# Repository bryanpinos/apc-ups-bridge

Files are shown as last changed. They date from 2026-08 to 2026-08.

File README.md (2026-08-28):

# apc-ups-bridge

Read an **APC UPS over USB HID** with an ESP32-S3 and republish it to **MQTT** with
Home Assistant auto-discovery.

No host computer involved. The UPS plugs into the ESP32, not into your NAS or server,
which frees the USB port and removes the "my UPS monitor died because the machine it
was plugged into went down" problem.

```
APC UPS ──USB──> MAX3421E FeatherWing ──SPI──> ESP32-S3 ──WiFi──> MQTT ──> Home Assistant
```

## Why

The usual way to monitor a UPS is NUT or apcupsd on a machine plugged into it. That
works, but it consumes a USB port on the very machine the UPS exists to protect, and
the monitoring dies exactly when the host does.

This project started after a UPS failed with a genuine internal fault and announced it
by beeping — because nothing was watching it. A battery was replaced that didn't need
replacing. Every fault flag this firmware exposes (`NeedReplacement`, `Overload`,
`ShutdownImminent`) was available over USB the whole time.

## What it publishes

| Kind | Entities |
|---|---|
| Sensors | battery %, runtime (s), load %, input voltage, battery voltage, self-test result |
| Binary sensors | on mains, on battery, needs replacement, overload, shutdown imminent, below capacity limit |
| Diagnostics | WiFi RSSI, uptime, free heap, USB device VID:PID, USB attached, HID mounted, board battery |

Plus the raw HID report descriptor on `<base>/hid/descriptor`, which is how you adapt
it to a UPS this code has never seen.

## Hardware

| Part | Notes |
|---|---|
| **Adafruit ESP32-S3 Feather** (8 MB, no PSRAM) | Any ESP32-**S2/S3** Feather works. Classic ESP32 does **not** — Adafruit TinyUSB requires S2/S3. |
| **Adafruit USB Host FeatherWing (MAX3421E)** | CS = pin 10, IRQ = pin 9, fixed. Onboard 5 V/1 A boost supplies VBUS. |
| USB cable from the UPS | APC ships an RJ50-to-USB-A cable; it plugs straight into the wing's USB-A jack. |
| LiPo cell *(optional)* | Lets the monitor outlive the UPS it is monitoring. The Feather's MAX17048 reports its own charge. |

Stack the wing on the Feather. There is no other wiring.

**Why the wing instead of the S3's native USB host?** The ESP32-S3's USB-OTG and
USB-Serial-JTAG share a single PHY, so using native host mode costs you the serial
console. The MAX3421E runs over SPI and leaves native USB free.

## Build

Requires [PlatformIO](https://platformio.org/).

```bash
cp src/secrets.h.example src/secrets.h   # then edit it
pio run -e feather -t upload             # first flash over USB
```

After the first flash everything is over the air:

```bash
export OTA_HOST=192.168.0.50   # the board's IP
export OTA_PW=your-ota-password
pio run -e ota -t upload
```

`secrets.h` is gitignored and holds WiFi, MQTT, OTA and the per-unit identity.

### Running more than one

Set a distinct `UNIT_ID` / `UNIT_HOST` / `UNIT_NAME` per board in `secrets.h`.
Home Assistant derives entity_ids from **`UNIT_NAME`**, not `UNIT_ID`, so pick it
deliberately — renaming later renames every entity.

## MQTT topics

Base topic is `apcups/<UNIT_ID>/`.

| Topic | Payload |
|---|---|
| `status` | `online` / `offline` (LWT, retained) |
| `ups` | JSON: all decoded UPS state |
| `diag` | JSON: RSSI, uptime, heap, IP, hostname, USB state |
| `boot` | JSON: reset reason, firmware version (retained) |
| `stage` | boot-stage beacon (retained) |
| `hid/descriptor` | raw HID report descriptor, hex (retained) |
| `log` | free-text log lines |
| `cmd` | accepts `dump`, `diag`, `discovery`, `reboot` |

## Running a self-test

```bash
mosquitto_pub -h broker -t 'apcups/<unit>/cmd' -m selftest        # quick
mosquitto_pub -h broker -t 'apcups/<unit>/cmd' -m selftest_deep
mosquitto_pub -h broker -t 'apcups/<unit>/cmd' -m selftest_abort
```

Watch `<base>/ups`: `discharging` flips true while the inverter carries the load,
then `test` settles on `passed` / `warning` / `error` / `aborted`.

**The report id must be prefixed to the SET_REPORT payload.** TinyUSB already puts
it in `wValue`, which is what the HID spec requires, and the transfer is *accepted*
either way — but this APC firmware silently ignores a payload-only write and does
nothing at all. Verified both directions: payload-only never starts a test,
id-prefixed always does. Consistent with GET_REPORT on this device returning
`21 06` (report id, then value).

**The UPS will refuse a test while the battery is recharging.** After a test it sits
around 93 % for a while, and a further request is accepted, resets the state to
"no test initiated", and then does nothing. That is the UPS protecting itself, not
a bug — wait for it to reach full charge.

⚠️ A self-test transfers everything on the battery-backed outlets to the inverter
for a few seconds. If the inverter is faulty, that load drops.

## Adapting to a different UPS

**The report map is model-specific — do not assume this one fits your UPS.** The
firmware dumps the descriptor unprompted, so adapting is mechanical:

```bash
mosquitto_sub -h broker -t 'apcups/<unit>/hid/descriptor' -C 1 > mine.hex
python3 tools/parse_hid.py mine.hex
```

`parse_hid.py` prints every field as *report id / bit offset / bit size / usage name /
logical range*. Then edit `POLL[]` and `applyReport()` in `src/main.cpp` to match.

### Reference map: APC Back-UPS Pro BR1500MS2 (`051d:0002`)

```
Rpt 22 (2B)  PresentStatus bitfield -- the entire status word in one read
   bit0 Charging   bit1 Discharging  bit2 ACPresent  bit3 BatteryPresent
   bit4 BelowRemainingCapacityLimit  bit5 ShutdownImminent
   bit6 RemainingTimeLimitExpired    bit7 CommunicationLost
   bit8 NeedReplacement              bit9 Overload   bit10 VoltageNotRegulated
Rpt 12 (3B)  RemainingCapacity (8b) + RunTimeToEmpty (16b, seconds)
Rpt 80 (1B)  PercentLoad %
Rpt 33 (1B)  Test result: 1 passed, 2 warning, 3 error, 4 aborted,
                          5 in progress, 6 no test initiated, 7 scheduled
Rpt 49 (2B)  Input voltage, volts
Rpt  9 (2B)  Battery voltage, raw/100 (24 V pack reads ~2730 -> 27.30 V)
Rpt 24 (1B)  AudibleAlarmControl 1..3
```

Battery voltage scaling differs by pack: a 12 V unit and a 24 V unit both report
hundredths, so check the value against the nominal pack voltage rather than trusting
the HID unit exponent, which APC populates oddly.

## Gotchas

Everything here cost real debugging time. If you are building something similar,
read this section first.

**`USBHost.task()` blocks forever by default.** The signature is
`task(uint32_t timeout_ms = UINT32_MAX, ...)`. Under FreeRTOS it sleeps until a USB
event arrives, so with nothing attached the first call in `loop()` never returns.
WiFi stays associated and pings still answer — because that is a different task — so
it looks like a network bug. **Always call `USBHost.task(0)`.**

**TinyUSB silently refuses report descriptors over 256 bytes.** `hid_host.c` checks
`report_desc_len > CFG_TUH_ENUMERATION_BUFSIZE` and calls the mount callback with
`NULL, 0`. That constant is not `#ifndef`-guarded, so `-D` cannot override it. APC
descriptors are ~1 kB. Fetch it yourself with the public
`tuh_descriptor_get_hid_report()` into your own buffer.

**Use the async USB APIs, never the `_sync` variants.** `loop()` is what calls
`USBHost.task(0)`, so a blocking sync call from `loop()` deadlocks the stack — nothing
is left to service it. Report polling is a one-request-in-flight state machine
advanced from `tuh_hid_get_report_complete_cb()`.

**`-DARDUINO_USB_MODE=1` is required.** Otherwise the Arduino core links its own
`libarduino_tinyusb.a` and you get dozens of `multiple definition of 'usbd_*'` link
errors against Adafruit TinyUSB.

**After an esptool USB flash, an ESP32-S3 can stay latched in ROM download mode.**
`Hard resetting via RTS pin` does not always clear it. It enumerates as Espressif
`303a:1001` and esptool talks to it happily while your app never runs. **Physically
unplug and replug USB.** Tell: with `ARDUINO_USB_MODE=0`, a running app must present
the board's own USB IDs — still seeing Espressif's means it is not executing.

**Do not trust the serial console for bring-up.** On this board HWCDC produced no
output at all, in either USB mode, via raw termios, `screen`, or `pio device monitor`.
The retained `stage` topic is what actually located the hang: publish a boot-stage
beacon at each step of `setup()` and read the last value that stuck.

**`WiFi.setHostname()` must be called before `WiFi.mode()`.** It only writes a static
buffer; the value is pushed to the interface inside `WiFiGenericClass::mode()`. Call
it after and you silently get the MAC-derived default. Worse, `WiFi.getHostname()`
reads that same buffer, so it reports the name you set even when the interface is
using the default — verify with mDNS instead.

**Pin PlatformIO's platform version.** `platform = espressif32` may resolve to a
release that requires a newer core than your stable PlatformIO. This project pins
`espressif32@6.9.0`.

## Repository layout

```
platformio.ini          build envs: feather (USB), ota (network), mintest (bisect)
case/                   parametric OpenSCAD enclosure + STLs
src/main.cpp            firmware
src/secrets.h.example   template for the gitignored secrets.h
tools/parse_hid.py      HID report descriptor parser -> field map
tools/br1500ms2.hex     reference descriptor from a BR1500MS2
```

The `mintest` env builds a bare sketch with no libraries — useful for bisecting
whether a problem is your code or the board.

## Enclosure

A parametric OpenSCAD case for the stacked Feather + wing lives in
[`case/`](case/), with ready-to-print STLs. Both short ends are open by design —
the two connectors sit at opposite ends and different heights, so no horizontal
parting line works for both. Print `ups-bridge-fittest.stl` first.

## License

MIT — see [LICENSE](LICENSE).

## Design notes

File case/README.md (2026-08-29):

# Enclosure

Parametric OpenSCAD case for an Adafruit ESP32-S3 Feather with a USB Host
FeatherWing stacked on top. Two parts, both print flat, no supports.

```bash
OPENSCAD=/Applications/OpenSCAD.app/Contents/MacOS/OpenSCAD   # macOS
$OPENSCAD -o stl/ups-bridge-base.stl    -D 'part="base"'    case.scad
$OPENSCAD -o stl/ups-bridge-lid.stl     -D 'part="lid"'     case.scad
$OPENSCAD -o stl/ups-bridge-fittest.stl -D 'part="fittest"' case.scad
```

Outer footprint is about **57 x 28 mm**; assembled height depends on your stack.

## Three parts: base, lid, face plate

Both USB ports exit the same end. That end is left **fully open** in the base and
lid, and closed afterwards by a **face plate** carrying one exact hole per
connector. The far end is a solid wall.

This is the only arrangement that gives two clean openings. A connector can only
pass through an opening that is open in the direction of assembly, so a
base/lid parting line would have to run through *both* connectors — impossible
when one sits at ~7 mm and the other at ~22 mm. Whichever you do not split
through becomes an ugly full-height slot.

The face plate also **retains the board**: the stack drops into the base, the lid
goes on, then the plate presses into the open end and blocks the only escape
route. No screws or clips.

Assembly order: stack into base → lid on → face plate pressed in.

Set `conn_end` to `+1` or `-1` to choose which end the connectors face, and
`face_fit` for the press-fit interference (0.25 mm per side by default).

### Size the openings for the PLUG, not the connector

The first revision sized each hole to the receptacle body and produced a plate
you could not plug into. Two things matter:

* **The plug's overmold is far larger than the receptacle** it mates with, and it
  has to clear the plate.
* **Plate thickness eats insertion depth.** Every millimetre of plate is a
  millimetre of plug shell that cannot reach the connector. The plate is now
  2.4 mm total (was 4.0), and each opening is chamfered on the outer face so an
  overmold can nose in rather than butting against a flat surface.

`usbc_w/h` and `usba_w/h` are therefore **plug overmold dimensions**, not
connector dimensions.

### Print the face plate first

It is a two-minute print and it is the only part whose fit depends on connector
positions rather than board outline. Offer it up to the assembled stack before
committing filament to the base and lid. Adjust `usbc_*` / `usba_*` if the holes
do not line up — `usbc_z` and `usba_z` are heights above the **cavity floor**,
and `usbc_y` / `usba_y` are lateral offsets from the centreline.

## Print the fit test first

`ups-bridge-fittest.stl` is a ~10 mm slice of the base — a few minutes of
filament. It proves the cavity width and the corner posts before you commit to
the full part.

It looks like two side rails with a small 90-degree tab at each end: those tabs
are the four corner posts the Feather rests on, and the board drops *between*
the rails and sits *on* the posts.

**The slice must be taller than the posts.** `fit_h` is derived as
`floor_t + under_h + pcb_t + 2`, which leaves 2 mm of wall standing above the
seated board. An earlier 6 mm version sliced the posts off level with the wall
tops, so a board laid in rested on top of everything and the width clearance
could not be tested at all.

## Dimensions

Measured on a real stack using plain male/female headers:

| Measurement | Value |
|---|---|
| Feather PCB bottom to wing PCB top | **14.0 mm** |
| Feather PCB bottom to top of USB-A shell | **21.0 mm** |

which give `stack_h = 10.8` (14.0 less two 1.6 mm PCBs) and `above_wing_h = 7.0`
(21.0 less 14.0). Plus 4.5 mm of clearance under the Feather for solder tails and
the LiPo lead, and 1.0 mm of headroom so the lid never presses on the USB-A shell:

```
cavity 26.5 mm tall   base 14.0 + lid 16.5   footprint 57.2 x 28.2 mm
```

**Re-measure if you use stacking headers** — they are taller than plain ones and
`stack_h` will grow.

## Suggested print settings

0.2 mm layers, 3 perimeters, 20% infill, PETG or PLA. No supports. The base
prints floor-down; the lid prints top-down (open side up).

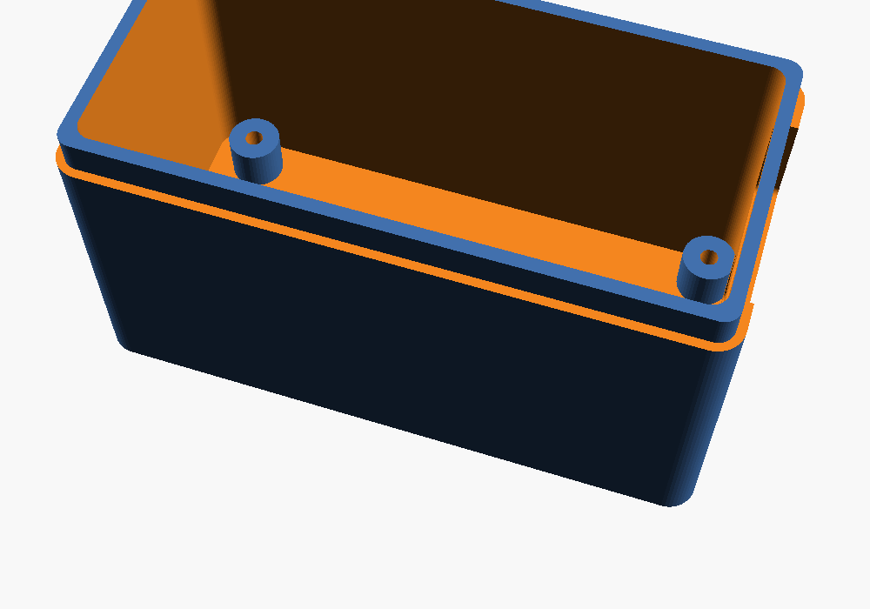
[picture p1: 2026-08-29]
case/preview-base-top.png

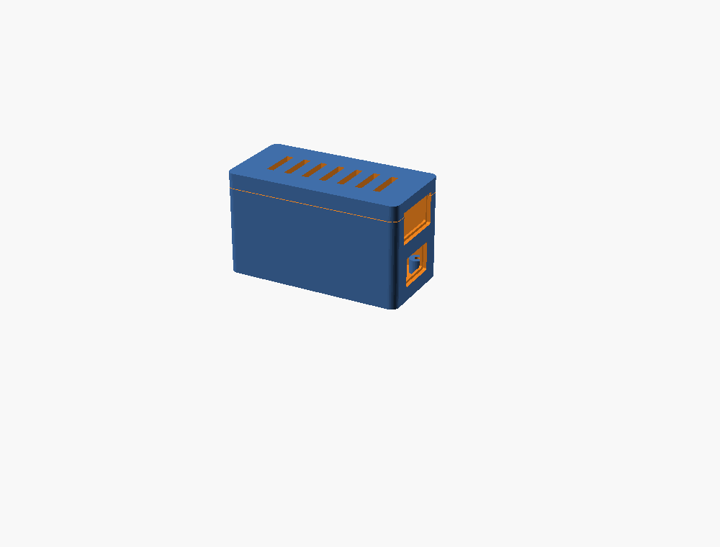
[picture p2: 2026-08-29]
case/preview-asm-0.png

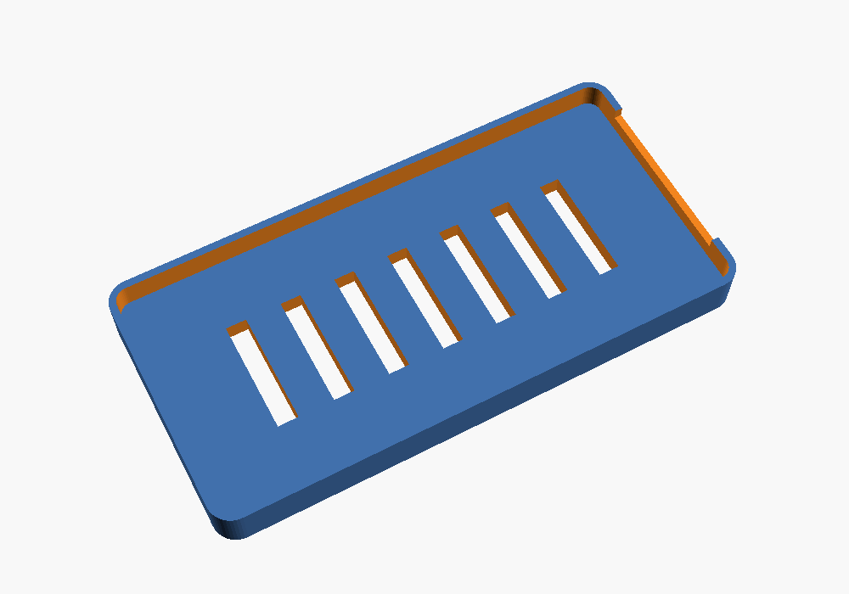
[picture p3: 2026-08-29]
case/preview-lid.png

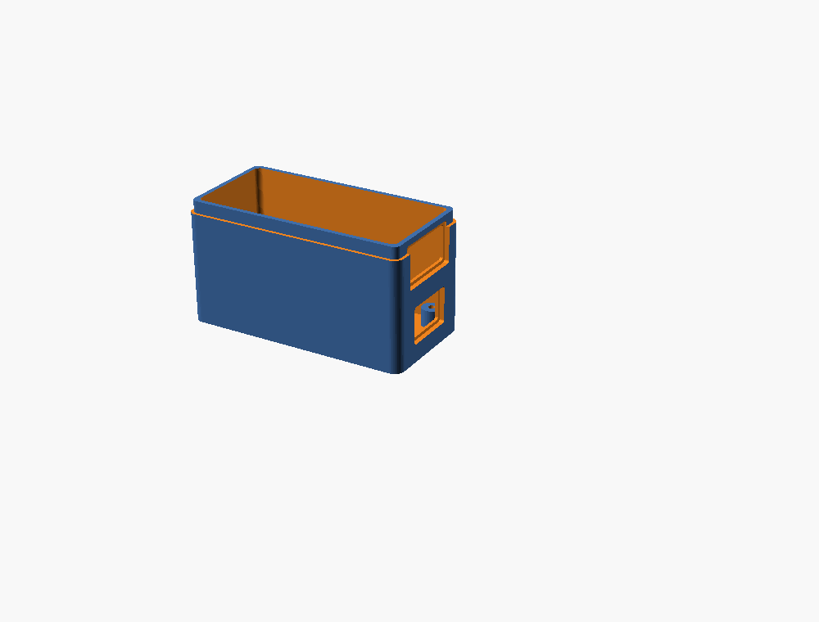
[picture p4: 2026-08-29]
case/preview-base.png

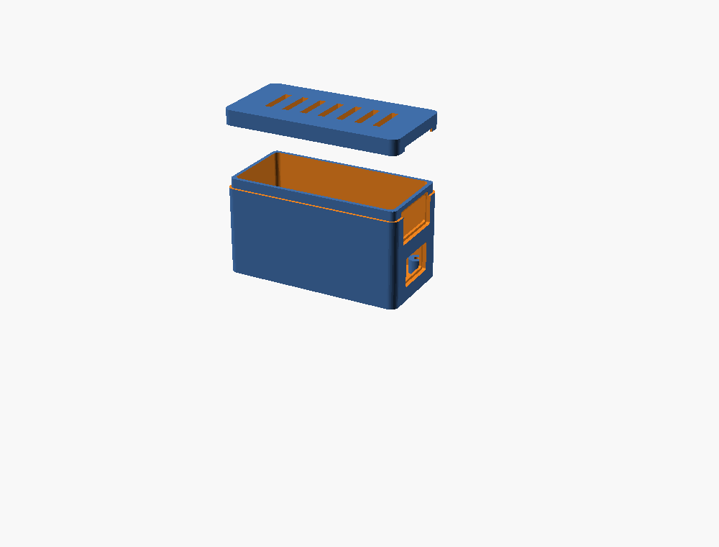
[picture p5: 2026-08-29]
case/preview-asm-1.png

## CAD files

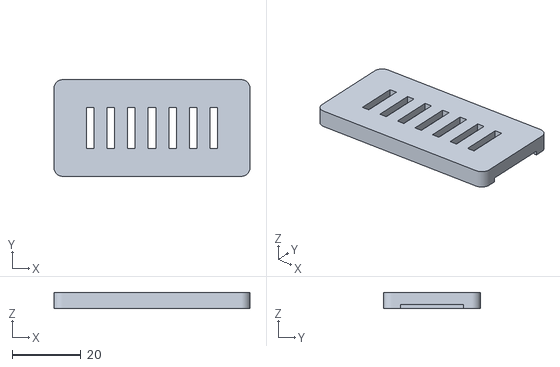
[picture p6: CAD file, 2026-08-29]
case/stl/ups-bridge-lid.stl
57.2 x 28.2 x 4.80

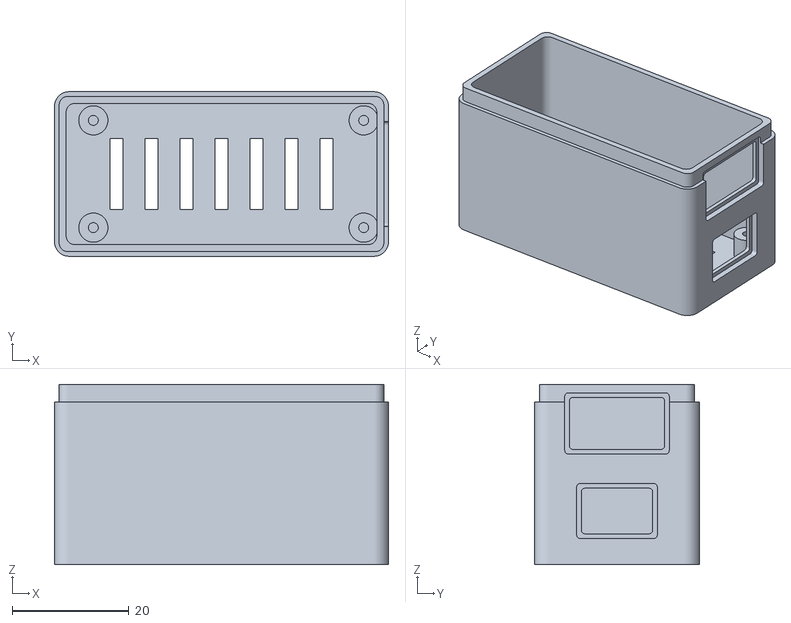
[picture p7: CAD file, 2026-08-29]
case/stl/ups-bridge-base.stl
57.2 x 28.2 x 30.9

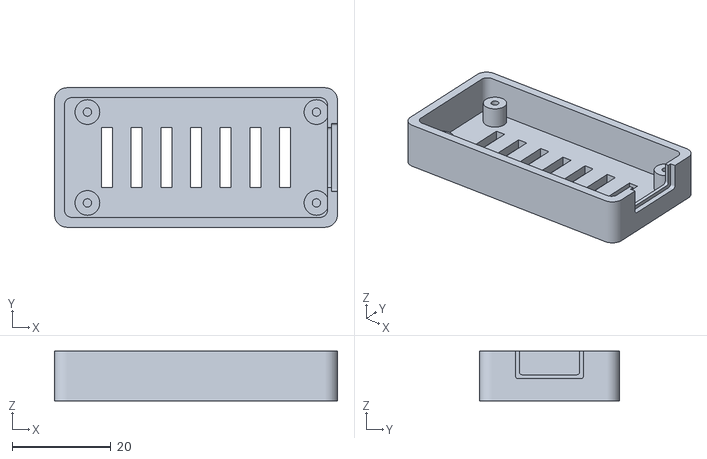
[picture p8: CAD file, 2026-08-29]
case/stl/ups-bridge-fittest.stl
57.2 x 28.2 x 10.1

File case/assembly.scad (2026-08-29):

// Assembly / exploded view. Not a printable part.
//   OpenSCAD -o out.png -D explode=1 assembly.scad
include <case.scad>;          // renders base() at the origin
explode = 0;
translate([0, 0, base_h + explode * 20]) lid();

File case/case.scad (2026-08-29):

// =============================================================================
//  UPS Bridge enclosure
//  Adafruit ESP32-S3 Feather + Adafruit USB Host FeatherWing (MAX3421E)
//  Companion to github.com/bryanpinos/apc-ups-bridge
//
//  Two parts, both print flat with no supports.
//
//  DESIGN NOTE: both USB ports exit the SAME end, and that end wall is SOLID,
//  carrying one hole per connector. The base is therefore full height and the
//  lid is only a cap.
//
//  This replaces an earlier three-part scheme (short base + tall lid + a separate
//  face plate pressed into an open end). That could not work: the slot that
//  opened the end removed the full width of it, so the face plate had nothing
//  left to register against, and the corner posts sat directly in its path.
//
//  The Feather goes in from above and is SCREWED to four bosses, which fixes its
//  position relative to the connector openings instead of leaving it to gravity.
//  Fit the Feather and its screws first, then plug the wing on top -- the wing
//  covers the Feather's mounting holes, and the 10.8 mm gap between the boards
//  clears the screw heads easily.
//    OpenSCAD -o out.stl -D 'part="base"'    case.scad
//    OpenSCAD -o out.stl -D 'part="lid"'     case.scad
//    OpenSCAD -o out.stl -D 'part="fittest"' case.scad   // 6 mm test slice
// =============================================================================

// ---------- BOARD DIMENSIONS -------------------------------------------------
// Feather spec is 50.8 x 22.86 mm; the Host wing is 52.0 x 22.8 x 8.8 mm.
// Cavity is sized to the larger footprint so both fit.
pcb_l        = 52.0;
pcb_w        = 23.0;
pcb_t        = 1.6;

// Measured on a real Feather + USB Host FeatherWing stack with plain male/
// female headers. Re-measure if you use stacking headers, which are taller.
stack_h      = 10.8;   // MEASURED: 14.0 overall (Feather PCB bottom -> wing PCB top)
                       //           minus two 1.6 mm PCBs = 10.8
above_wing_h = 7.4;    // MEASURED: 21.4 (Feather PCB bottom -> USB-A top)
                       //           minus 14.0 (to wing PCB top) = 7.4
headroom     = 3.0;    // air above the USB-A shell. Sets how much wall is left
                       // above the USB-A hole, whose top edge lands at 28.65 from
                       // the outer floor. Below ~2.3 the hole breaks out of the
                       // top of the base entirely.

under_h      = 4.5;    // clearance below the Feather for solder tails / LiPo lead

// ---------- CONNECTOR END ----------------------------------------------------
// Both USB ports exit the same end, through a solid 2 mm wall. The plug overmold
// -- not the receptacle -- is what has to pass through: the connectors sit ~2 mm
// behind the outer face, and a USB-A plug only has ~12 mm of shell against ~12 mm
// of insertion depth, so if the overmold could not enter the hole the plug would
// stop 2 mm short of seating. Size these to the actual cables that will live in
// this case; a chunky charging lead can be half again the size of a slim one.
conn_end     = 1;      // +1 or -1: which end the connectors face

usbc_plug_w  = 11.0;   // measured
usbc_plug_h  = 6.6;
usba_plug_w  = 15.1;   // measured
usba_plug_h  = 7.7;
plug_clear   = 1.2;    // total added, i.e. 0.6 per side. Deliberately loose: the
                       // centre heights below close to about +/-0.5 mm, and a
                       // plug that rattles slightly still mates -- one that is
                       // 0.4 mm proud of the hole does not.

// Connector CENTRE heights, from the FEATHER PCB BOTTOM -- the same datum as the
// 14.0 and 21.4 stack measurements. Closed out from three caliper readings:
//   wing PCB top          = 14.0   -> USB-A shell bottom (it sits flush)
//   USB-A top             = 21.4   -> USB-A spans 14.0..21.4, centre 17.7
//   clear gap between the = 10.2   -> USB-C top = 14.0 - 10.2 = 3.8, and it sits
//   two connector shells              on the Feather PCB top (1.6), so 1.6..3.8,
//                                     centre 2.7
// Note the USB-C body works out only 2.2 mm proud of the PCB, which means it is
// a mid-mount part sitting in a board cutout, not a 3.2 mm top-mount one. The
// three measurements close on each other, so trust them over the datasheet.
usbc_c       = 2.7;
usba_c       = 17.7;

usbc_w       = usbc_plug_w + plug_clear;
usbc_h       = usbc_plug_h + plug_clear;
usba_w       = usba_plug_w + plug_clear;
usba_h       = usba_plug_h + plug_clear;

// An undefined variable here does NOT fail: OpenSCAD warns, discards the whole
// transform, and draws the feature at the origin. That shipped a face plate with
// its USB-C opening 3.2 mm low. Fail loudly instead.
assert(is_num(usbc_c) && is_num(usba_c) && is_num(usbc_w) && is_num(usba_h),
       "connector opening dimensions must all be numbers");

// ---------- SHELL ------------------------------------------------------------
wall         = 2.0;
floor_t      = 2.0;
gap          = 0.6;    // per-side clearance around the PCB
corner_r     = 2.5;
// The lid drops OVER a rebated step on the tray rim. A short-lived inner-spigot
// version was tried and abandoned: it was given 0.3 mm per-side CLEARANCE, which
// aligns the lid and does nothing to hold it, so the lid simply fell off.
// Retention here is friction on the step, which means the bore must be sized to
// the step as PRINTED, not as modelled -- this printer runs internal dimensions
// roughly 0.4 mm large, enough on its own to turn a press fit into a rattle.
lip_h        = 3.0;    // rebate depth on the tray rim
lip_t        = 1.2;    // wall thickness left at the step

step_l       = 55.6;   // MEASURE the printed tray's step; nominal cav_l + 2*lip_t
step_w       = 26.6;   // MEASURE; nominal cav_w + 2*lip_t
skirt_fit    = 0.0;    // total added to the bore. 0 = line-to-line on the
                       // measured step. Negative = interference.
skirt_h      = 2.8;    // 0.2 mm shy of lip_h so the plate seats on the step top,
                       // not on the shoulder
vent_slots   = true;

part = "base";
$fn = 48;

// ---------- DERIVED ----------------------------------------------------------
cav_l     = pcb_l + 2*gap;
cav_w     = pcb_w + 2*gap;
cav_h     = under_h + pcb_t + stack_h + pcb_t + above_wing_h + headroom;
out_l     = cav_l + 2*wall;
out_w     = cav_w + 2*wall;
feather_z = under_h;                       // PCB underside above inner floor
wing_z    = under_h + pcb_t + stack_h;
// The base is now the whole box: it has to be tall enough to contain the USB-A
// hole in its own end wall. The lid is just a cap over the top.
base_h    = floor_t + cav_h;
lid_h     = floor_t;

// Rounded rectangular prism, centred in X/Y, sitting on z=0.
module rrect(l, w, h, r) {
  linear_extrude(height = h)
    offset(r = r) offset(delta = -r) square([l, w], center = true);
}

// ---------- SCREW BOSSES ------------------------------------------------------
// Four bosses aligned to the FEATHER's mounting holes (the wing stacks above and
// is not fastened). Bosses replace the plain corner posts the board used to rest
// on: screwing it down also pins it against the connector openings, so the plug
// heights stay true.
//
// Both measured: 3.5 mm from the board edge to the FAR side of the mounting
// hole (the same to the long and the short edge), and 2.5 mm hole diameter. The
// hole CENTRE is therefore 3.5 - 2.5/2 = 2.25 mm in from each edge.
feather_l    = 50.8;   // Feather spec, NOT the 52.0 wing footprint the cavity uses
feather_w    = 22.86;
hole_edge    = 3.5;    // MEASURED: board edge -> far side of the mounting hole
board_hole_d = 2.5;    // MEASURED
hole_inset   = hole_edge - board_hole_d/2;

boss_od      = 5.0;
screw_pilot  = 1.7;    // M2 self-tapping into PLA. Drill out to 2.05 for a
                       // machine screw and a nut, or 1.5 for a tighter bite.

// The Feather sits hard against the connector end, so its openings line up: its
// end edge is at the cavity end and the bosses are referenced back from there.
module posts() {
  for (px = [conn_end * (cav_l/2 - hole_inset),
             conn_end * (cav_l/2 - feather_l + hole_inset)],
       py = [-1, 1])
    translate([px, py * (feather_w/2 - hole_inset), floor_t])
      difference() {
        cylinder(h = under_h, d = boss_od);
        translate([0, 0, -0.5]) cylinder(h = under_h + 1, d = screw_pilot);
      }
}
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

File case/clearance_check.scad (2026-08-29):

// Test fixture, not a printable part. Places the lid where it actually sits and
// intersects it against real geometry. Any facets = interference.
//   OpenSCAD -o out.stl -D 'part="none"' -D 'check="realplug"' clearance_check.scad
// NOTE: an envelope that exactly matches a hole yields a ZERO-VOLUME artifact
// from coincident faces -- always check the facet count, not just whether an STL
// got written.
include <case.scad>;
check = "realplug";

module plug_envelope(c, w, h) {
  z = floor_t + under_h + c;
  translate([conn_end * (out_l/2 + 6), 0, z])
    rotate([0, 90, 0]) linear_extrude(height = 24, center = true) rr2(h, w, 0.6);
}
module board_volume() {
  translate([conn_end * (cav_l/2 - pcb_l/2), 0,
             floor_t + under_h + (pcb_t + stack_h + pcb_t + above_wing_h)/2])
    cube([pcb_l, pcb_w, pcb_t + stack_h + pcb_t + above_wing_h], center = true);
}
if (check == "realplug")            // actual plug overmolds through the assembly
  intersection() {
    union() { base(); translate([0,0,base_h]) lid(); }
    union() { plug_envelope(usbc_c, usbc_plug_w, usbc_plug_h);
              plug_envelope(usba_c, usba_plug_w, usba_plug_h); }
  }
if (check == "fit")                 // lid skirt vs tray step
  intersection() { base(); translate([0,0,base_h]) lid(); }
if (check == "board")               // lid vs the installed stack
  intersection() { translate([0,0,base_h]) lid(); board_volume(); }

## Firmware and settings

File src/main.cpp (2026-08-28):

// APC UPS -> MQTT bridge  |  v0.1 "diagnostics + OTA"
//
// Adafruit ESP32-S3 Feather (8MB, no PSRAM) + USB Host FeatherWing (MAX3421E)
//   MAX3421E: SPI, CS = pin 10, IRQ = pin 9   (FeatherWing defaults)
//   Native USB-C stays free for serial console -- host runs on rhport 1.
//
// This build does NOT decode UPS data yet. It brings up WiFi + OTA + MQTT,
// publishes diagnostics, and dumps the HID report descriptor of whatever
// USB device is attached so the decode layer can be written against it.

#include <Arduino.h>
#include <WiFi.h>
#include <ESPmDNS.h>
#include <ArduinoOTA.h>
#include <PubSubClient.h>
#include <ArduinoJson.h>
#include <Wire.h>
#include <Adafruit_MAX1704X.h>
#include "Adafruit_TinyUSB.h"
#include "SPI.h"
#include "secrets.h"
#include <esp_system.h>

// ----------------------------------------------------------------- config
static const char *FW_VERSION = "1.5.0";
// ===================== PER-UNIT IDENTITY =====================
// Define these in secrets.h (gitignored) to build a second bridge. Defaults below
// are placeholders so the project builds out of the box.
//   UNIT_ID   MQTT client id, topic base, HA unique_id prefix. Underscores ok.
//   UNIT_HOST Network hostname. RFC-1123: letters/digits/hyphens ONLY.
//   UNIT_NAME HA device name. NOTE: HA derives entity_ids from THIS, not UNIT_ID.
#ifndef UNIT_ID
#define UNIT_ID    "ups_bridge"
#endif
#ifndef UNIT_HOST
#define UNIT_HOST  "ups-bridge"
#endif
#ifndef UNIT_NAME
#define UNIT_NAME  "UPS Bridge"
#endif
// =============================================================

static const char *DEV_ID   = UNIT_ID;
static const char *DEV_NAME = UNIT_NAME;
static const char *NET_HOST = UNIT_HOST;

#define MAX3421_CS   10
#define MAX3421_INT   9

static const uint32_t DIAG_INTERVAL_MS   = 15000;
static const uint32_t MQTT_RETRY_MS      = 5000;
static const size_t   MQTT_BUFFER_BYTES  = 8192;

// ----------------------------------------------------------------- state
Adafruit_USBH_Host USBHost(&SPI, MAX3421_CS, MAX3421_INT);
Adafruit_MAX17048  fuelGauge;
bool fuelGaugeOk = false;

WiFiClient   net;
PubSubClient mqtt(net);

static char tBase[48], tStatus[80], tDiag[80], tDesc[80], tLog[80], tCmd[80], tStage[80], tBoot[80], tUps[80];

static volatile bool usbAttached = false;
static uint16_t usbVid = 0, usbPid = 0;
static uint8_t  usbDaddr = 0;

static bool     hidMounted = false;
static uint8_t  hidDaddr = 0, hidIdx = 0;
static uint16_t hidDescLen = 0;
static uint8_t  hidDesc[2048];
static bool     hidDescWanted = false;   // TinyUSB skipped it (>256B enum buf)
static bool     hidDescInFlight = false;
static bool     hidDescDirty = false;

struct UpsState {
  bool valid = false;
  // status flags
  bool charging=false, discharging=false, acPresent=false, batteryPresent=false;
  bool belowCapLimit=false, shutdownImminent=false, timeLimitExpired=false;
  bool commLost=false, needReplacement=false, overload=false, voltNotRegulated=false;
  int  capacity=-1;        // %
  long runtime=-1;         // seconds
  int  load=-1;            // %
  int  test=-1;
  long vin=-1;             // raw
  long vbatt=-1;           // raw
  int  alarm=-1;
} ups;

static uint32_t pollTimeouts = 0;
// loop() section timing -- worst case since the last diag publish
static uint32_t tmUsb = 0, tmOta = 0, tmMqtt = 0, tmPoll = 0, tmLoop = 0;
static uint8_t  setBuf[8];
static bool     rawDump = false;
static bool upsTest(uint8_t mode);   // defined with the poll machine

static uint32_t lastDiag = 0, lastMqttTry = 0;
static uint32_t bootMs = 0;

// ----------------------------------------------------------------- helpers
static void logf(const char *fmt, ...) {
  char buf[256];
  va_list ap; va_start(ap, fmt);
  vsnprintf(buf, sizeof(buf), fmt, ap);
  va_end(ap);
  Serial.println(buf);
  if (mqtt.connected()) mqtt.publish(tLog, buf);
}

static void publishDescriptor() {
  if (!hidDescLen || !mqtt.connected()) return;
  // hex-encode; 1024 bytes max -> 2048 chars, inside the 4k buffer
  static char hex[4200];
  size_t n = hidDescLen > sizeof(hidDesc) ? sizeof(hidDesc) : hidDescLen;
  for (size_t i = 0; i < n; i++) sprintf(hex + i * 2, "%02x", hidDesc[i]);
  hex[n * 2] = 0;
  mqtt.publish(tDesc, hex, true);
  logf("published HID report descriptor: %u bytes", (unsigned)hidDescLen);
  hidDescDirty = false;
}


// ----------------------------------------------------------------- wifi diagnostics
static const char *wifiStatusStr(int st) {
  switch (st) {
    case WL_IDLE_STATUS:     return "IDLE";
    case WL_NO_SSID_AVAIL:   return "NO_SSID_AVAIL";
    case WL_SCAN_COMPLETED:  return "SCAN_COMPLETED";
    case WL_CONNECTED:       return "CONNECTED";
    case WL_CONNECT_FAILED:  return "CONNECT_FAILED (auth?)";
    case WL_CONNECTION_LOST: return "CONNECTION_LOST";
    case WL_DISCONNECTED:    return "DISCONNECTED";
    default:                 return "UNKNOWN";
  }
}

static const char *authStr(int a) {
  switch (a) {
    case WIFI_AUTH_OPEN:            return "OPEN";
    case WIFI_AUTH_WEP:             return "WEP";
    case WIFI_AUTH_WPA_PSK:         return "WPA_PSK";
    case WIFI_AUTH_WPA2_PSK:        return "WPA2_PSK";
    case WIFI_AUTH_WPA_WPA2_PSK:    return "WPA/WPA2_PSK";
    case WIFI_AUTH_WPA2_ENTERPRISE: return "WPA2_ENTERPRISE";
    case WIFI_AUTH_WPA3_PSK:        return "WPA3_PSK";
    case WIFI_AUTH_WPA2_WPA3_PSK:   return "WPA2/WPA3_PSK";
    default:                        return "other";
  }
}

// Does NOT print the SSID itself -- only whether the configured one is visible.
// The ESP32-S3 radio is 2.4 GHz only, so "NOT FOUND" usually means the SSID is
// 5 GHz-only, hidden, or misspelled.
static void wifiScanReport() {
  int n = WiFi.scanNetworks(false, true);
  Serial.printf("[wifi] scan: %d networks visible on 2.4GHz\n", n);
  bool found = false;
  for (int i = 0; i < n; i++) {
    if (WiFi.SSID(i) == String(WIFI_SSID)) {
      found = true;
      Serial.printf("[wifi] configured SSID FOUND  ch=%d rssi=%d auth=%s\n",
                    WiFi.channel(i), (int)WiFi.RSSI(i),
                    authStr(WiFi.encryptionType(i)));
      break;
    }
  }
  if (!found)
    Serial.println("[wifi] configured SSID NOT FOUND on 2.4GHz "
                   "(5GHz-only? hidden? typo?)");
  WiFi.scanDelete();
}

// ----------------------------------------------------------------- HA discovery
static void haSensor(const char *key, const char *name, const char *unit,
                     const char *devclass, const char *tmpl, bool diagnostic) {
  char topic[160];
  snprintf(topic, sizeof(topic), "homeassistant/sensor/%s_%s/config", DEV_ID, key);

  JsonDocument d;
  d["name"] = name;
  d["uniq_id"] = String(DEV_ID) + "_" + key;
  d["stat_t"] = tDiag;
  d["val_tpl"] = tmpl;
  d["avty_t"] = tStatus;
  d["pl_avail"] = "online";
  d["pl_not_avail"] = "offline";
  if (unit && *unit)         d["unit_of_meas"] = unit;
  if (devclass && *devclass) d["dev_cla"] = devclass;
  if (diagnostic)            d["ent_cat"] = "diagnostic";
  JsonObject dev = d["dev"].to<JsonObject>();
  dev["ids"][0] = DEV_ID;
  dev["name"] = DEV_NAME;
  dev["mf"] = "DIY";
  dev["mdl"] = "ESP32-S3 Feather + MAX3421E";
  dev["sw"] = FW_VERSION;

  char out[768];
  size_t n = serializeJson(d, out, sizeof(out));
  mqtt.publish(topic, (const uint8_t *)out, n, true);
}

static void haBinary(const char *key, const char *name, const char *devclass,
                     const char *tmpl) {
  char topic[160];
  snprintf(topic, sizeof(topic), "homeassistant/binary_sensor/%s_%s/config", DEV_ID, key);

  JsonDocument d;
  d["name"] = name;
  d["uniq_id"] = String(DEV_ID) + "_" + key;
  d["stat_t"] = tDiag;
  d["val_tpl"] = tmpl;
  d["pl_on"] = "true";
  d["pl_off"] = "false";
  d["avty_t"] = tStatus;
  d["pl_avail"] = "online";
  d["pl_not_avail"] = "offline";
  if (devclass && *devclass) d["dev_cla"] = devclass;
  d["ent_cat"] = "diagnostic";
  JsonObject dev = d["dev"].to<JsonObject>();
  dev["ids"][0] = DEV_ID;
  dev["name"] = DEV_NAME;
  dev["mf"] = "DIY";
  dev["mdl"] = "ESP32-S3 Feather + MAX3421E";
  dev["sw"] = FW_VERSION;

  char out[768];
  size_t n = serializeJson(d, out, sizeof(out));
  mqtt.publish(topic, (const uint8_t *)out, n, true);
}


static void haUps() {
  struct S { const char *k,*n,*u,*dc,*t; };
  static const S sensors[] = {
    {"capacity","UPS battery","%","battery","{{ value_json.capacity }}"},
    {"runtime","UPS runtime","s","duration","{{ value_json.runtime_s }}"},
    {"load","UPS load","%","power_factor","{{ value_json.load_pct }}"},
    {"input_v","UPS input voltage","V","voltage","{{ value_json.input_v }}"},
    {"battery_v","UPS battery voltage","V","voltage","{{ value_json.battery_v }}"},
    {"test","UPS self-test",NULL,NULL,"{{ value_json.test }}"},
  };
  for (auto &x : sensors) {
    char topic[160];
    snprintf(topic, sizeof(topic), "homeassistant/sensor/%s_%s/config", DEV_ID, x.k);
    JsonDocument d;
    d["name"] = x.n; d["uniq_id"] = String(DEV_ID) + "_" + x.k;
    d["stat_t"] = tUps; d["val_tpl"] = x.t;
    d["avty_t"] = tStatus; d["pl_avail"]="online"; d["pl_not_avail"]="offline";
    if (x.u)  d["unit_of_meas"] = x.u;
    if (x.dc) d["dev_cla"] = x.dc;
    JsonObject dev = d["dev"].to<JsonObject>();
    dev["ids"][0]=DEV_ID; dev["name"]=DEV_NAME; dev["mf"]="DIY";
    dev["mdl"]="ESP32-S3 Feather + MAX3421E"; dev["sw"]=FW_VERSION;
    char out[768]; size_t n = serializeJson(d, out, sizeof(out));
    mqtt.publish(topic, (const uint8_t*)out, n, true);
  }
  struct B { const char *k,*n,*dc,*t; };
  static const B bins[] = {
    {"ac_present","UPS on mains","power","{{ value_json.ac_present }}"},
    {"discharging","UPS on battery","battery_charging","{{ value_json.discharging }}"},
    {"need_replacement","UPS battery needs replacement","problem","{{ value_json.need_replacement }}"},
    {"overload","UPS overload","problem","{{ value_json.overload }}"},
    {"shutdown_imminent","UPS shutdown imminent","problem","{{ value_json.shutdown_imminent }}"},
    {"below_cap_limit","UPS below capacity limit","problem","{{ value_json.below_cap_limit }}"},
  };
  for (auto &x : bins) {
    char topic[160];
    snprintf(topic, sizeof(topic), "homeassistant/binary_sensor/%s_%s/config", DEV_ID, x.k);
    JsonDocument d;
    d["name"]=x.n; d["uniq_id"]=String(DEV_ID)+"_"+x.k;
    d["stat_t"]=tUps; d["val_tpl"]=x.t; d["pl_on"]="true"; d["pl_off"]="false";
    d["avty_t"]=tStatus; d["pl_avail"]="online"; d["pl_not_avail"]="offline";
    if (x.dc) d["dev_cla"]=x.dc;
    JsonObject dev = d["dev"].to<JsonObject>();
    dev["ids"][0]=DEV_ID; dev["name"]=DEV_NAME; dev["mf"]="DIY";
    dev["mdl"]="ESP32-S3 Feather + MAX3421E"; dev["sw"]=FW_VERSION;
    char out[768]; size_t n = serializeJson(d, out, sizeof(out));
    mqtt.publish(topic, (const uint8_t*)out, n, true);
  }
  logf("HA UPS discovery published");
}

static void publishDiscovery() {
  haSensor("rssi", "WiFi RSSI", "dBm", "signal_strength", "{{ value_json.rssi }}", true);
  haSensor("uptime", "Uptime", "s", "duration", "{{ value_json.uptime_s }}", true);
  haSensor("heap", "Free heap", "B", "data_size", "{{ value_json.heap_free }}", true);
  haSensor("batt_v", "Backup battery voltage", "V", "voltage", "{{ value_json.batt_v }}", true);
  haSensor("batt_pct", "Backup battery", "%", "battery", "{{ value_json.batt_pct }}", true);
  haSensor("usb_id", "USB device", "", "", "{{ value_json.usb_id }}", true);
  haBinary("usb_attached", "USB device attached", "connectivity", "{{ value_json.usb_attached }}");
  haBinary("hid_mounted", "HID interface mounted", "connectivity", "{{ value_json.hid_mounted }}");
  haUps();
  logf("HA discovery published");
}

// ----------------------------------------------------------------- diagnostics
static void publishDiag() {
  JsonDocument d;
  d["fw"]          = FW_VERSION;
  d["uptime_s"]    = (millis() - bootMs) / 1000;
  d["rssi"]        = WiFi.RSSI();
  d["ip"]          = WiFi.localIP().toString();
  d["hostname"]    = WiFi.getHostname();
  d["heap_free"]   = ESP.getFreeHeap();
  d["heap_min"]    = ESP.getMinFreeHeap();
  d["usb_attached"] = usbAttached ? "true" : "false";
  d["hid_mounted"]  = hidMounted ? "true" : "false";
  d["hid_desc_len"] = hidDescLen;
  d["poll_timeouts"] = pollTimeouts;
  d["t_loop_ms"] = tmLoop;  d["t_usb_ms"] = tmUsb;  d["t_ota_ms"] = tmOta;
  d["t_mqtt_ms"] = tmMqtt;  d["t_poll_ms"] = tmPoll;
  tmLoop = tmUsb = tmOta = tmMqtt = tmPoll = 0;
  d["ups_valid"]    = ups.valid ? "true" : "false";

  char idbuf[16] = "none";
  if (usbAttached) snprintf(idbuf, sizeof(idbuf), "%04x:%04x", usbVid, usbPid);
  d["usb_id"] = idbuf;

  if (fuelGaugeOk) {
    d["batt_v"]   = serialized(String(fuelGauge.cellVoltage(), 3));
    d["batt_pct"] = serialized(String(fuelGauge.cellPercent(), 1));
  } else {
    d["batt_v"]   = nullptr;
    d["batt_pct"] = nullptr;
  }

  char out[512];
  size_t n = serializeJson(d, out, sizeof(out));
  mqtt.publish(tDiag, (const uint8_t *)out, n, false);
}

// ----------------------------------------------------------------- MQTT
static void onMqtt(char *topic, byte *payload, unsigned int len) {
  String cmd; for (unsigned i = 0; i < len; i++) cmd += (char)payload[i];
  cmd.trim();
  logf("cmd: %s", cmd.c_str());
  if (cmd == "dump")        publishDescriptor();
  else if (cmd == "diag")   publishDiag();
  else if (cmd == "discovery") publishDiscovery();
  else if (cmd == "reboot") { mqtt.publish(tStatus, "offline", true); delay(200); ESP.restart(); }
  else if (cmd == "selftest")      logf("self-test quick: %s", upsTest(1) ? "submitted" : "submit FAILED");
  else if (cmd == "selftest_deep") logf("self-test deep: %s",  upsTest(2) ? "submitted" : "submit FAILED");
  else if (cmd == "selftest_abort")logf("self-test abort: %s", upsTest(3) ? "submitted" : "submit FAILED");
  else if (cmd == "raw33") { rawDump = true; logf("will dump raw report 33"); }
}

static void mqttConnect() {
  if (millis() - lastMqttTry < MQTT_RETRY_MS) return;
  lastMqttTry = millis();
  if (!mqtt.connect(DEV_ID, nullptr, nullptr, tStatus, 0, true, "offline")) return;
  mqtt.publish(tStatus, "online", true);
  mqtt.subscribe(tCmd);
  publishDiscovery();
  publishDiag();
  if (hidDescLen) publishDescriptor();
  Serial.printf("MQTT connected to %s:%d\n", MQTT_HOST, MQTT_PORT);
}

// ----------------------------------------------------------------- TinyUSB callbacks
extern "C" {

void tuh_mount_cb(uint8_t daddr) {
  usbDaddr = daddr;
  usbAttached = true;
  tuh_vid_pid_get(daddr, &usbVid, &usbPid);
  Serial.printf("[usb] attached addr=%u  %04x:%04x\n", daddr, usbVid, usbPid);
}

void tuh_umount_cb(uint8_t daddr) {
  (void)daddr;
  usbAttached = false;
  hidMounted = false;
  hidDescLen = 0;
  usbVid = usbPid = 0;
  Serial.printf("[usb] detached addr=%u\n", daddr);
}

void tuh_hid_mount_cb(uint8_t daddr, uint8_t idx,
                      uint8_t const *report_desc, uint16_t desc_len) {
  hidDaddr = daddr; hidIdx = idx; hidMounted = true;
  if (desc_len == 0 || report_desc == NULL) {
    // TinyUSB skips descriptors larger than CFG_TUH_ENUMERATION_BUFSIZE (256).
    // APC descriptors exceed that, so fetch it ourselves into a bigger buffer.
    hidDescLen = 0;
    hidDescWanted = true;
    Serial.println("[hid] descriptor skipped by stack (>256B) - will fetch manually");
  } else {
    hidDescLen = desc_len;
    uint16_t n = desc_len > sizeof(hidDesc) ? sizeof(hidDesc) : desc_len;
    memcpy(hidDesc, report_desc, n);
    hidDescDirty = true;
  }
  Serial.printf("[hid] mounted daddr=%u idx=%u desc_len=%u\n", daddr, idx, desc_len);
}

void tuh_hid_umount_cb(uint8_t daddr, uint8_t idx) {
  (void)daddr; (void)idx;
  hidMounted = false;
  Serial.println("[hid] unmounted");
}

void tuh_hid_report_received_cb(uint8_t daddr, uint8_t idx,
                                uint8_t const *report, uint16_t len) {
  (void)daddr; (void)idx; (void)report; (void)len;
  // v0.1: not consuming interrupt reports yet
}

} // extern "C"



static const char *resetReasonStr(esp_reset_reason_t r) {
  switch (r) {
    case ESP_RST_POWERON:  return "POWERON";
    case ESP_RST_EXT:      return "EXT_RESET";
    case ESP_RST_SW:       return "SW_RESTART";
    case ESP_RST_PANIC:    return "PANIC (crash)";
    case ESP_RST_INT_WDT:  return "INT_WDT";
    case ESP_RST_TASK_WDT: return "TASK_WDT";
    case ESP_RST_WDT:      return "OTHER_WDT";
    case ESP_RST_BROWNOUT: return "BROWNOUT (power)";
    case ESP_RST_DEEPSLEEP:return "DEEPSLEEP";
    case ESP_RST_SDIO:     return "SDIO";
    default:               return "UNKNOWN";
  }
}

// Boot-stage beacon: a headless board must be able to say how far it got.
// Published retained, so the last successful stage survives a hang.
static void stage(const char *s) {
  Serial.printf("[stage] %s\n", s);
  if (mqtt.connected()) { mqtt.publish(tStage, s, true); mqtt.loop(); }
}

// Blocking-with-timeout connect used during setup only.
static bool mqttConnectBlocking(uint32_t timeoutMs) {
  uint32_t t0 = millis();
  while (millis() - t0 < timeoutMs) {
    if (mqtt.connected()) return true;
    if (mqtt.connect(DEV_ID, nullptr, nullptr, tStatus, 0, true, "offline")) {
      mqtt.publish(tStatus, "online", true);
      mqtt.subscribe(tCmd);
      return true;
    }
    delay(500);
  }
  return false;
}


// Manual report-descriptor fetch (async; a sync call from loop() would deadlock
// the USB stack, since loop() is also what services USBHost.task()).
static void descFetchDone(tuh_xfer_t *xfer) {
  hidDescInFlight = false;
  if (xfer->result == XFER_RESULT_SUCCESS) {
    hidDescLen = (uint16_t)xfer->actual_len;
    hidDescDirty = true;
    hidDescWanted = false;
    Serial.printf("[hid] fetched report descriptor: %u bytes\n", hidDescLen);
  } else {
    Serial.printf("[hid] descriptor fetch failed, result=%d\n", (int)xfer->result);
  }
}

static void hidDescFetchTick() {
  if (!hidDescWanted || hidDescInFlight || !hidMounted) return;
  tuh_itf_info_t info;
  if (!tuh_hid_itf_get_info(hidDaddr, hidIdx, &info)) return;
  hidDescInFlight = true;
  bool ok = tuh_descriptor_get_hid_report(hidDaddr, info.desc.bInterfaceNumber,
                                          0x22 /* HID report descriptor */, 0,
                                          hidDesc, sizeof(hidDesc),
                                          descFetchDone, 0);
  if (!ok) { hidDescInFlight = false; }
  else     { Serial.println("[hid] descriptor fetch requested"); }
}


// ----------------------------------------------------------------- UPS polling
// Report map derived from this unit's own 1049-byte descriptor (tools/parse_hid.py).
// tuh_hid_get_report() is ASYNC: one request in flight, completion arrives in
// tuh_hid_get_report_complete_cb(), then we advance to the next report.
struct PollItem { uint8_t id; uint8_t len; };
static const PollItem POLL[] = {
  {22, 2},   // PresentStatus bitfield (11 flags)
  {12, 3},   // RemainingCapacity(8) + RunTimeToEmpty(16)
  {80, 1},   // PercentLoad %
  {33, 1},   // Test result 0..6
  {49, 2},   // input Voltage
  { 9, 2},   // battery Voltage
  {24, 1},   // AudibleAlarmControl 1..3
};
static const uint8_t POLL_N = sizeof(POLL) / sizeof(POLL[0]);

static uint8_t  pollIdx = 0;
static bool     pollInFlight = false;
static uint32_t lastPoll = 0;
static uint32_t pollStart = 0;     // for the in-flight watchdog
static uint8_t  pollBuf[16];


static const char *testStr(int t) {
  switch (t) {
    case 1: return "passed";      case 2: return "warning";
    case 3: return "error";       case 4: return "aborted";
    case 5: return "in progress"; case 6: return "no test initiated";
    case 7: return "scheduled";   default: return "unknown";
  }
}

// GET_REPORT may or may not echo the report id as byte 0 -- handle both.
static const uint8_t *payload(const uint8_t *b, uint16_t len, uint8_t id, uint16_t *outLen) {
  if (len && b[0] == id) { *outLen = len - 1; return b + 1; }
  *outLen = len; return b;
}
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
void loop() {
  uint32_t loopStart = millis();

  TIME_IT(tmUsb, USBHost.task(0))   // 0 = non-blocking; default UINT32_MAX blocks forever
  TIME_IT(tmOta, ArduinoOTA.handle())

  // Verbose while offline: a headless box must explain itself over serial.
  static uint32_t lastWifiLog = 0, lastRetry = 0;
  static uint8_t  offlineTicks = 0;
  if (WiFi.status() != WL_CONNECTED) {
    if (millis() - lastWifiLog >= 3000) {
      lastWifiLog = millis();
      int st = WiFi.status();
      Serial.printf("[wifi] status=%d %s  (fw %s, up %lus)\n",
                    st, wifiStatusStr(st), FW_VERSION,
                    (unsigned long)((millis() - bootMs) / 1000));
      if (++offlineTicks % 5 == 0) wifiScanReport();
    }
    if (millis() - lastRetry >= 20000) {
      lastRetry = millis();
      Serial.println("[wifi] retrying begin()");
      WiFi.disconnect();
      WiFi.begin(WIFI_SSID, WIFI_PASSWORD);
    }
  }

  if (WiFi.status() == WL_CONNECTED) {
    if (!mqtt.connected()) TIME_IT(tmMqtt, mqttConnect())
    else                   TIME_IT(tmMqtt, mqtt.loop())
  }

  hidDescFetchTick();
  TIME_IT(tmPoll, pollTick())
  if (hidDescDirty && mqtt.connected()) publishDescriptor();

  if (millis() - lastDiag >= DIAG_INTERVAL_MS) {
    lastDiag = millis();
    if (mqtt.connected()) publishDiag();
  }

  uint32_t d = millis() - loopStart;
  if (d > tmLoop) tmLoop = d;
}

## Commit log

2026-08-28 Read an APC UPS over USB HID on an ESP32-S3 and publish to MQTT
    ESP32-S3 Feather + MAX3421E USB Host FeatherWing acts as a USB host to the
    UPS, decodes the HID Power Device pages, and publishes to MQTT with Home
    Assistant auto-discovery. Frees the USB port on the machine the UPS protects,
    and keeps monitoring alive independently of that host.
    Includes a HID report descriptor parser so the firmware can be adapted to
    other UPS models, and a reference decode map for the APC BR1500MS2.
2026-08-28 Add parametric OpenSCAD enclosure for the Feather + USB Host wing
    Two-part case, both halves print flat without supports. Both short ends are
    left open deliberately: the Feather's USB-C and the wing's USB-A sit at
    opposite ends and very different heights, so no single horizontal parting line
    lets both connectors clear a wall. Open ends also remove the need to guess at
    connector positions and improve airflow.
    Includes a 6 mm fit-test slice so cavity dimensions can be checked cheaply
    before committing filament to the full part.
    [case.scad, ups-bridge-base.stl, ups-bridge-fittest.stl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]
2026-08-28 Add a watchdog to the report poll state machine
    tuh_hid_get_report() is asynchronous and only one request is in flight at a
    time. If its completion callback never arrives -- the device re-enumerates, or
    a transfer is dropped when UPS power is switched -- pollInFlight stayed true
    forever and polling wedged permanently. Diagnostics kept publishing, so the
    failure was silent: everything looked healthy except that UPS data stopped.
    Time out an in-flight request after 2s, advance to the next report, and expose
    poll_timeouts and ups_valid in the diag payload so a stall is visible.
    [main.cpp]
2026-08-28 Add UPS self-test command over MQTT
    New cmd payloads: selftest, selftest_deep, selftest_abort, writing the Test
    field (report 33 / usage 0x84:0x58).
    The report id must be prefixed to the SET_REPORT payload. TinyUSB already
    places it in wValue per the HID spec, and the control transfer is ACCEPTED
    either way, but this APC firmware silently ignores a payload-only write and
    never starts a test. Verified in both directions; matches GET_REPORT on this
    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
2026-08-28 Fix intermittent MQTT drops; instrument loop timing; measured case dimensions
    PubSubClient default socketTimeout is 15s, identical to its default keepalive,
    so a single stalled socket read consumes the entire keepalive window and the
    broker disconnects the client. Every Home Assistant entity went unavailable
    each time, because the LWT fired. Raise keepalive to 60s, cut socket timeout
    to 5s.
    Loop instrumentation was added first to rule the firmware out: worst-case
    section times now publish in diag as t_loop_ms / t_usb_ms / t_ota_ms /
    t_mqtt_ms / t_poll_ms. Max loop time measured 7ms, which is what pointed at
    the socket layer rather than a stall.
    Case: stack_h corrected to 10.8mm from a real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
    [case.scad, ups-bridge-base.stl, ups-bridge-fittest.stl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]
2026-08-28 Case: both stack dimensions now measured, not assumed
    Measured on the real stack with plain headers: 14.0mm from Feather PCB bottom
    to wing PCB top, and 21.0mm to the top of the USB-A shell. That gives
    stack_h = 10.8 and above_wing_h = 7.0. The USB-A figure cross-checks against
    Adafruit's 8.8mm overall wing spec to within 0.4mm.
    Adds a 1.0mm headroom parameter so the lid cannot bear on the USB-A shell,
    which the previous geometry would have done at exact contact.
    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
    [case.scad, ups-bridge-base.stl, ups-bridge-fittest.stl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]
2026-08-28 Fix fit-test coupon: it was too short to test anything
    The corner posts stand floor_t + under_h = 6.5mm, but the coupon sliced the
    base at a hardcoded 6.0mm. That truncated the posts level with the wall tops,
    so a board laid into the coupon rested on top of everything with no wall
    above it, and the width clearance -- the entire point of the fit test -- could
    not be checked.
    Derive the height instead: floor_t + under_h + pcb_t + 2, giving ~10.1mm and
    leaving 2mm of wall above the seated board.
    Also documents what the coupon looks like, since two rails with a 90-degree
    tab at each end is not self-explanatory: the tabs are the corner posts, and
    the board goes between the rails and on top of t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
    [case.scad, ups-bridge-fittest.stl]
2026-08-29 Case: connectors are on one end, so close the other and retain the board
    Both USB ports exit the same end of the assembled stack, not opposite ends as
    previously assumed. The connector end now has a central full-height slot
    (conn_slot_w, 17mm) that clears both the Feather USB-C and the wing USB-A,
    while the material either side remains as corner pillars. The far end is a
    solid wall.
    This fixes a real defect: with both ends fully open nothing stopped the board
    sliding out, and it was held only by cable tension. The stack now drops in from
    above and is captured lengthwise between the pillars and the far wall, so no
    screw or clip is required.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
    [case.scad, ups-bridge-base.stl, ups-bridge-fittest.stl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]
2026-08-29 Case: separate face plate with discrete connector openings
    Replaces the full-height connector slot with a third part carrying one exact
    hole per USB port, which is the only way to get two clean openings. A connector
    can only pass through an opening that is open in the direction of assembly, so
    a horizontal base/lid parting line would need to run through both a ~7mm and a
    ~22mm connector at once. Leaving that end open and closing it afterwards with a
    face plate sidesteps the constraint entirely.
    The plate also retains the board, replacing the corner pillars: the stack drops
    into the base, the lid goes on, and the plate presses into the only remaining
    opening.
    headroom raised 1.0 -> 2.5mm. I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
    [case.scad, ups-bridge-base.stl, ups-bridge-face.stl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]
2026-08-29 Face plate: size openings for the plug, and halve the plate thickness
    The first print could not be plugged into. Two causes, both mine:
    Openings were sized to the receptacle body rather than the mating plug. A
    plug's overmold is much larger than the connector it mates with and has to
    clear the plate to let the shell seat. USB-C 9.6x4.0 -> 12.0x6.5, USB-A
    14.0x7.6 -> 15.5x8.0.
    Plate thickness directly consumes plug insertion depth, and at 4.0mm total
    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
    [case.scad, ups-bridge-face.stl]
2026-08-29 Face plate: derive openings from measured plug dimensions
    Openings are now computed from measured plug overmold sizes plus a single
    clearance parameter, rather than guessed. USB-C 11.0x6.6 and USB-A 15.1x7.7
    measured; plug_clear 0.8 total (0.4 per side) gives 11.8x7.4 and 15.9x8.5.
    The previous guess had usbc_h at 6.5 against a 6.6mm plug, so the USB-C
    opening was actually smaller than the plug it had to pass. Deriving from
    measurements removes that class of error.
    Chamfer trimmed 2.4 -> 1.6mm to keep material above the USB-A opening.
    [case.scad, ups-bridge-face.stl]
2026-08-29 case: fix silently-dropped USB-C hole, apply measured connector heights
    usbc_y was referenced in face() but never defined. OpenSCAD does not fail on
    an unknown variable -- it warns, discards the entire translate(), and cuts the
    hole at the plate origin. The printed face plate therefore had its USB-C
    opening 3.2 mm low, which widened the bridge between the two openings from
    6.4 mm to 14.1 mm. Define usbc_y and assert all four opening coordinates are
    numbers so this cannot recur silently.
    Connector centre heights now closed out from three caliper readings rather
    than assumed shell heights: wing PCB top 14.0, USB-A top 21.4, clear gap
    between the shells 10.2 -> USB-C 1.6..3.8 (centre 2.7), USB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
    [case.scad, ups-bridge-base.stl, ups-bridge-face.stl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]
2026-08-29 case: add assembly/exploded view
    The face plate's relationship to the base and lid is not obvious from the
    three parts on their own -- it is a separate piece spanning the full assembled
    height that closes the open end of BOTH, and it must go on after the lid.
    Render it so the assembly order is self-evident.
    [assembly.scad]
2026-08-29 case: drop the face plate, put the connector holes in a solid end wall
    The three-part scheme (short base + tall lid + a face plate pressed into an
    open end) could not have worked, for two independent reasons:
    * conn_slot() removed the FULL WIDTH of the connector end, side walls
    included, so the face plate's interference plug had nothing left to
    register against -- it was seating on air.
    * the corner posts sit at the cavity corners from z 2.0..6.5, directly in
    the path of anything entering from that end.
    A third bug was found on the way: conn_slot() cut from z = floor_t, which is
    the cavity floor in the BASE's frame but +2.0 in the LID's, leaving the lid's
    skirt (-3.0..0) an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
    [assembly.scad, case.scad, ups-bridge-base.stl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]
2026-08-29 case: screw the Feather to four bosses instead of resting it on posts
    The plain corner posts left the board held down by gravity alone, with 3 mm of
    air above the USB-A shell -- fine on a shelf, but nothing kept the connectors
    registered to their openings. Four bosses on the Feather's mounting holes fix
    the board in all three axes, so the measured opening heights stay true.
    Hole centres come from a measured 3.5 mm from the board edge to the FAR side of
    the mounting hole (same to the long and short edge), less half the hole
    diameter. board_hole_d is assumed 2.0, putting the centre at 2.5 mm in from
    each edge -- exactly the 0.1" the Feather spec calls for, so measurement and
    spec agree. Param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
    [case.scad, ups-bridge-base.stl, ups-bridge-fittest.stl]
2026-08-29 case: mounting holes measured at 2.5 mm, boss centres to 2.25 mm inset
    Both inputs are now measured rather than one assumed: 3.5 mm board edge to the
    far side of the hole, 2.5 mm hole diameter -> centre 2.25 mm in from each edge.
    Bosses move 0.25 mm outward from the assumed-2.0 placement.
    All clearances still positive at the tighter inset: 0.42 mm to the side walls,
    0.35 mm to the nearest floor vent, 2.15 mm from the rear boss to the far wall,
    and 0.58 mm between the boss and the USB-C bore. The forward boss now embeds
    0.25 mm into the end wall and simply fuses with it.
    [case.scad, ups-bridge-base.stl, ups-bridge-fittest.stl]
2026-08-29 case: lid locates on an inner spigot, not an outer skirt
    The outer skirt sat in a rebate cut into the base's OUTER wall -- the same wall
    the connector holes are in. At this stack height the rebate floor (27.90) fell
    below the top of the USB-A opening (28.65), so the skirt cut across the top
    0.75 mm of the port: the plug would still enter, but the lid seam crossed the
    opening and most of the vertical tolerance was gone.
    Replaced with a spigot ring that drops into the top of the cavity instead. It
    shares nothing with the connector wall, so the base now keeps full-thickness
    wall for 2.25 mm above the USB-A opening, and outside the joint is a clean butt
    line on the rim. The spigot hangs above t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
    [case.scad, clearance_check.scad, ups-bridge-base.stl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]
2026-08-29 case: lid wraps the tray rim; restore the rebate so tray and lid agree
    Two faults, one of them mine to own.
    The inner-spigot lid was given 0.3 mm per-side CLEARANCE. Clearance aligns a
    lid; it does not hold one. There was no interference and no catch anywhere in
    the design, so it simply fell off. Retention was never actually specified.
    Worse, removing the rim rebate in 0d4ade1 silently orphaned every tray already
    printed from 768e388, which still has it -- and it was asserted at the time
    that the printed tray was "still good". It was not: a rebated tray plus a
    spigot lid is two halves of two different designs. The rebate is restored so
    base() once again describes the tray that physically e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
    [case.scad, clearance_check.scad, ups-bridge-base.stl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]
2026-09-06 build: add env for the 4MB/2MB-PSRAM Feather (PID 5477)
    The 8MB no-PSRAM board this was developed on (5323) is out of stock, so record
    that the 4MB/2MB-PSRAM variant is a drop-in and why.
    All three variants (5323 / 5477 / 5885) share one PCB design, so the pinout is
    identical. Both board definitions use qio flash mode, not opi -- the 2MB PSRAM
    is QUAD and shares the flash bus, so it does NOT consume GPIO33-37 the way octal
    PSRAM would. SPI to the MAX3421E (SCK36/MOSI35/MISO37) is unaffected. PSRAM goes
    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
2026-09-12 v1.6.2: on-device status page, wing detection, per-unit secrets
    Status page served by the device itself at http://<unit>/ with the same data as
    JSON at /api. Everything inline -- no CDN, no external fonts: these boards sit
    on a LAN that may have no route out, and a status page needing the internet to
    render is useless exactly when you want it. Costs 34.6 KB flash, 2.5 KB RAM,
    and 1 ms of loop time.
    Colour is never the only signal. Every state carries a word too (OK / FAULT /
    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
2026-09-12 v1.7.0: self-test buttons on the web UI
    Quick / deep / abort, mapped onto the same upsTest() path the MQTT cmd topic
    already uses.
    POST only, deliberately. A self-test transfers the UPS to its inverter for a few
    seconds, so everything on its battery outlets rides on the inverter while it
    runs -- on the aquarium unit that is life support, on the basement one the cable
    modem. That must never be reachable by a GET a browser prefetch, a crawler or a
    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
2026-09-21 v1.7.1: timer-driven ups publish so a poll timeout can never silence readings
    Both deployed units stalled identically: 9 days up, diag every 15 s with
    every health flag true, poll_timeouts=1, and no ups message at all. The
    reading was only published from the USB completion callback when the poll
    sweep wrapped; the timeout and submit-failure paths advance the sweep
    themselves, so one late completion phase-shifted it and the callback never
    saw the wrap again.
    - publish ups from loop() every 10 s when any report was applied since the
    last publish (immediately after boot); the callback no longer publishes
    - diag gains ups_age_s (seconds since last ups publish, -1 = never) as the
    liveness si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
2026-09-21 v1.7.2: abort the stuck control transfer on a poll timeout, self-restart if still stale
    v1.7.1 published on a timer but only when a report had been applied, and
    after a timed-out GET_REPORT no report is ever applied again: TinyUSB still
    owns the transfer, the control endpoint stays busy, every later
    tuh_hid_get_report() is refused (uncounted until now), and polling stops
    while usb_attached/hid_mounted read true. The aquarium unit did it again
    2h48m after the 1.7.1 flash with the same poll_timeouts=1 signature.
    - on a poll timeout call tuh_edpt_abort_xfer(daddr, 0), which resets the
    control stage to idle
    - count refused submits (diag submit_fails) and aborts (diag ep0_aborts)
    - stale-poll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
2026-09-26 v1.7.3: recover the USB host chip in software instead of restarting blind
    A self-restart (v1.7.2) does not reset the MAX3421E, and the aquarium unit
    came back from one unable to see its UPS for three days until a physical
    power cycle. Two recovery ladders now go through the chip itself:
    - mounted but no report applied: 120 s ep0 abort, 300 s host deinit/init
    (both pulse CHIPRES), 600 s restart as last resort
    - device missing after having had one: 60 s bus reset, then host
    deinit/init every 60 s, restart only after 10 min and only if a device
    was ever mounted so a UPS-less board never reboot-loops
    - diag gains bus_resets, host_reinits, usb_lost_s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
2026-10-09 v1.8.0: read and set APC input sensitivity (report 53)
    Polls APCSensitivity (report 53, usage 0xFF86:0x61) with the other feature
    reports, publishes it as "sensitivity"/"sens_code", exposes an HA select, and
    adds sens_low / sens_medium / sens_high commands.
    Why: "low" widens the input voltage window the UPS accepts before transferring
    to battery. The aquarium unit refused Powerwall island power for five minutes
    at 120 V -- the inverter's output sat outside the default medium window, so the
    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
2026-10-16 v1.9.1: set FDUPSPI before probing the MAX3421E
    probeMax3421() read the REVISION register without first writing PINCTL. The
    MAX3421E powers up in HALF-duplex SPI, where MISO is not driven at all -- the
    chip talks back over MOSI -- so every read returned 0x00 on a perfectly healthy
    chip. hcd_init() sets PINCTL_FDUPSPI on its first line for exactly this reason;
    the probe skipped it.
    The failure was deterministic, not intermittent, which is what made it so
    convincing as a hardware fault:
    - after an OTA or `cmd reboot` the chip RETAINS PINCTL from the previous
    hcd_init, so the probe read 0x13 and a real osc_ms
    - after a genuine power cycle PINCTL resets to half duplex, so the probe rea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
2026-10-16 Pick the strongest AP instead of the first one found (1.11.0)
    The ESP32 default scan is WIFI_FAST_SCAN: it walks channels in order and
    associates with the FIRST AP matching the SSID, ignoring signal strength.
    Channel 1 is scanned first, so any AP on channel 1 wins however distant it
    is -- and all four APs here share one SSID.
    Result: the basement bridge associated with the shed U7 Mesh at -88 dBm and
    negotiated 1 Mbps, the 802.11b fallback rate, while a wired U7 Lite sat
    line-of-sight on channel 6. That link was too weak to carry an OTA image
    (espota died at 14%), so the unit had silently lost remote updates. The
    aquarium bridge had made the same choice at -76 dBm.
    WIFI_ALL_CHANNEL_SCAN +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
2026-10-17 Log every candidate AP and expose the boot scan remotely (1.11.2)
    wifiScanReport() broke at the first SSID match, which is worse than useless
    with one SSID across four APs: the whole question is which candidates existed
    and how they compared. Without the full list you cannot distinguish "it chose
    badly" from "nothing better was audible". Now it lists every matching AP with
    BSSID, channel and RSSI, strongest first, and runs once at boot rather than
    only while offline.
    The list is also kept in `boot_scan` and published in diag, so it is readable
    over HTTP and MQTT. Native USB CDC detaches on reset, so the boot lines are
    effectively uncapturable over the cable -- and a bad association is preci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
2026-10-17 Publish a build stamp so --check can answer "is my fix running?"
    These boards have no reachable console, so the only way to know which code is
    on one is to ask it over the network. Two failures tonight were invisible
    without that: the basement UPS bridge sat un-OTA-able at 1 Mbps, and the EMS
    panel silently missed firmware for weeks while publishing normally and looking
    perfectly healthy -- its uptime was the only tell.
    tools/build_id.py stamps -D BUILD_ID (git short sha + UTC build time, with
    -dirty when the tree is not clean) and the diag payload now carries it, so
    `ota-flash --check <device>` reports running-vs-repo. A hand-maintained version
    string could not do this: it reads the same f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
2026-10-17 Fix a silently truncated MQTT diag payload, and guard against it
    Adding boot_scan in 1.11.2 pushed the diag JSON past its 640-byte buffer.
    serializeJson() truncates to fit and returns the SHORT length, so the bridge
    published invalid JSON (no closing brace) every 15 s and every consumer -- Home
    Assistant's MQTT diag sensors among them -- simply stopped parsing it. Nothing
    errored anywhere.
    It went unnoticed because that change was verified over HTTP /api, which
    serializes through a different path and was always complete. Checking the
    interface I had not changed would have caught it immediately.
    Buffer is now 1536 bytes against a measured ~1.1 kB payload, and publishes go
    through publishJso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
